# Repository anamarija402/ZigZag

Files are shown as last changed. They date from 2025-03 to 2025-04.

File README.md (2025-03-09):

## RadionaOrg ZigZag badge

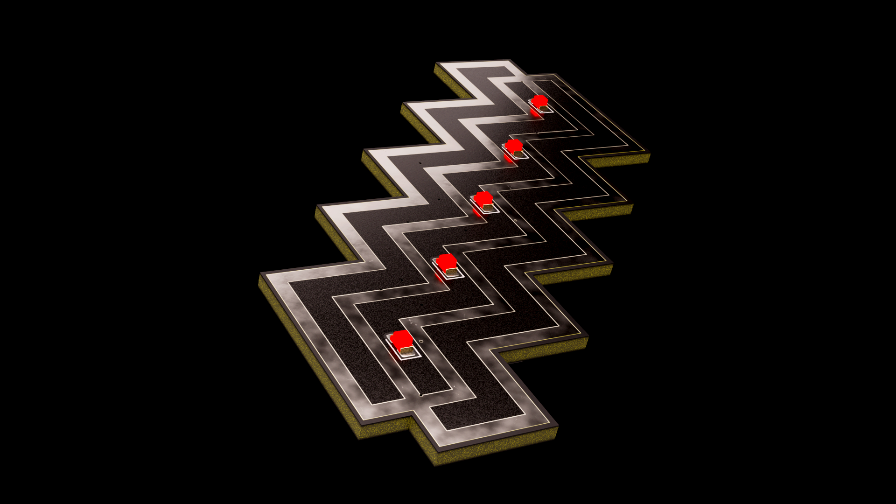
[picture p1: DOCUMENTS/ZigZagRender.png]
ZigZag


### Request and starting point

We got request from BSidesZG to design some blink LED badge with some interesting task to solve.

https://www.bsideszagreb.com/

As badge may slightly change over time here is aditional README for BSidesZG

BSidesZG README

Starting point for our badge was RVPC from Olimex, we have preserved most of schematics, and added LEDs

The EURO 1.00 Risc-V personal computer with VGA and Keyboard and Woz like monitor. The purpose of this project is to make educational platform which people can use to learn RISCV assembler and experiment like in the old days in 1980s :)

https://www.olimex.com/Products/Retro-Computers/RVPC/open-source-hardware

We whare also inspired with BalCCon badge that is using same chip.

https://2k25.balccon.org/

### Few of ideas we wanted to test

- [x] Keep it simple
- [x] Keep it low cost
- [x] Should solderable by hand
- [x] Input and outputs are needed
- [x] Tasks can be quickly changed added
- [x] It needs to be cheap to order assembled
- [x] Use most standard COIN CELL battery CR2032
- [x] Unique design that is connected to Radiona (ZigZag)
- [x] Badge should not draing to much current so it can survive conference day

### Why 5 LEDs?

With less then 5 LEDs we could do blinky, but with 5 we can do PoV

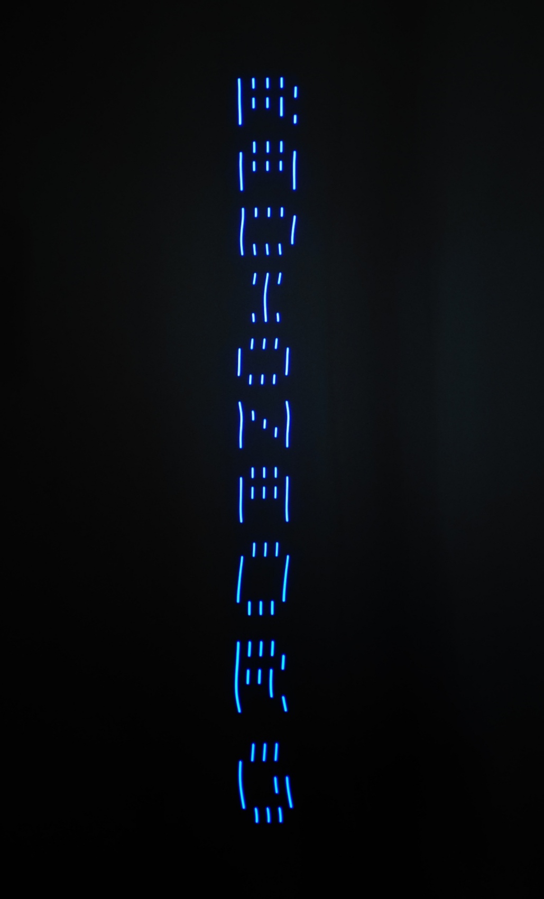
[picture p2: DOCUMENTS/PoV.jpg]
PoV


As we have BLUE and RED team, we have tested BLUE and RED LEDs.

RED LED are consuming less, and morse is better readable.

### Why Only one button?

We only have 6 pins, and we did not want to intraduce any aditinal chip.

And there are many things we can do with one button.

Considerring that we can have short press, long press, longer press, double press, tripple press - you get the point that one button should be enough for everything...

### Why those component and why 0603

We are using 0603 resistors and 0805 LEDs as they are still hand solderable, and we are using those on ULX3S so we can recycle components from scraped boards...

### Assembly

We wanted to confirm hand assembly, and low batch DIY assembly so we did first badge by hand, and rest of 69 badges with stencil. 
We baked first batch in oven but also checked paper stancil + hot air, and all works fine.

Paper is just 80g color paper. Diode laser cuts some colors better so we are using orange one.

For PCB holder we are using cuted cardboard

And for BOTTOM side we are using standoff cutter from hammer paper.

Applying paste to front side

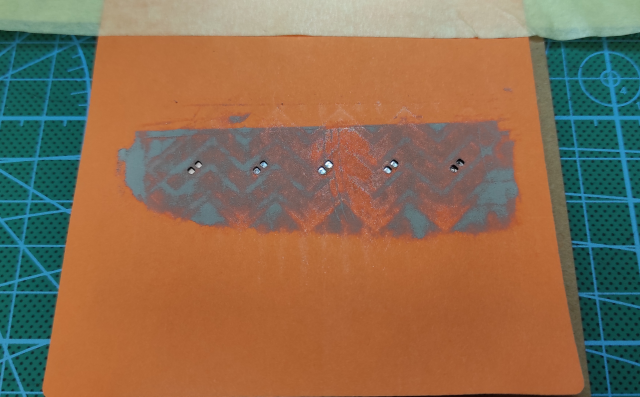
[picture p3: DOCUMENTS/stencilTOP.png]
Applying paste for LEDs


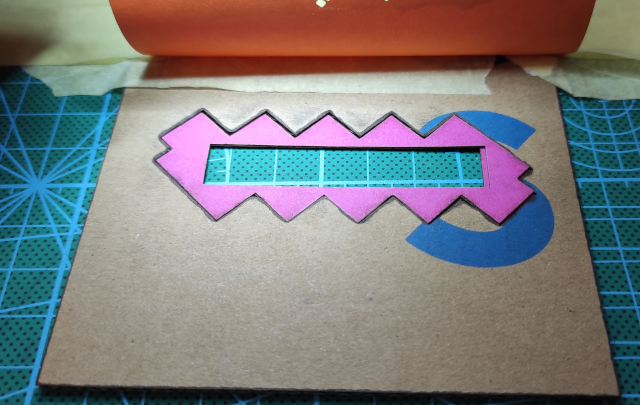
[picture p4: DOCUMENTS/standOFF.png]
StandOFF


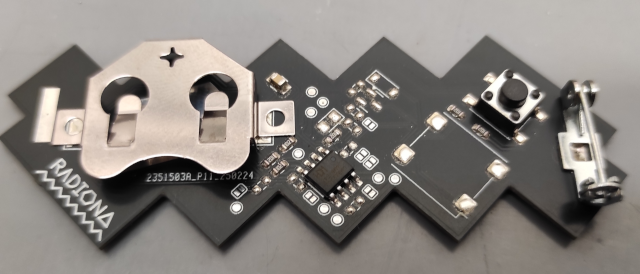
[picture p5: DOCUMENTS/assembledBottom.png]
Asembled Bottom


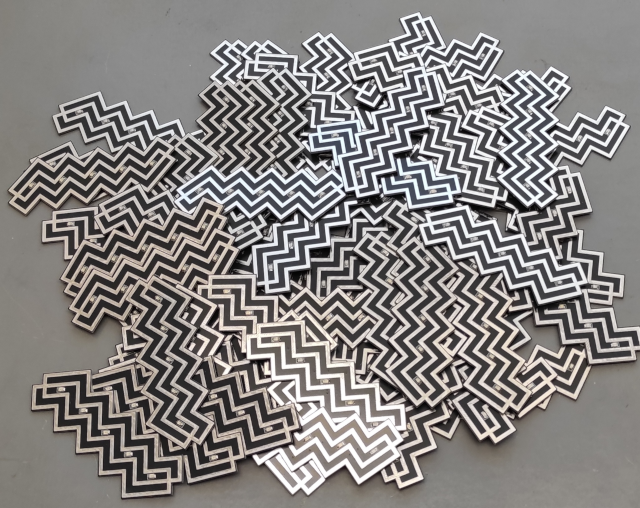
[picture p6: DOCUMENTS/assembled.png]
Assebled


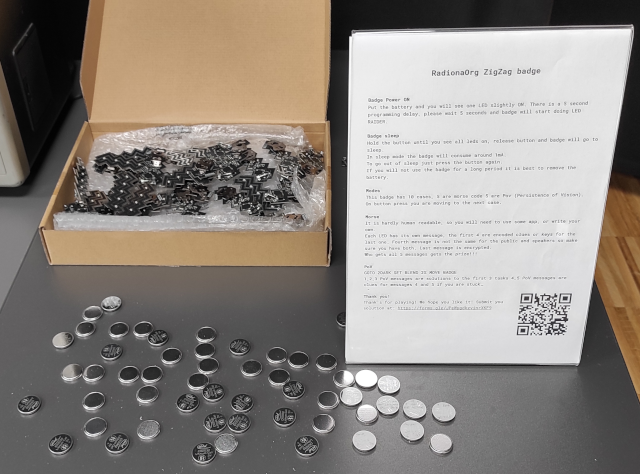
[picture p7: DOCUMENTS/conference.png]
Conference


### Implemented features

- [x] Fancy raider blinking
- [x] Morse used for output messages
- [x] PoV used for clues and solutions
- [x] Short button press
- [x] Long button press
- [ ] Other types of button presses
- [x] Sleep mode
- [ ] Deep sleep mode

### Make it hackable!

We did not want to remove any RVPC component so with moving few resistors and closing jumpers you could even have RVPC with VGA, PS2 and speaker...

### Badge software

https://github.com/RadionaOrg/ZigZag/tree/main/SOFTWARE/PlatformIO/ZigZag

We are using VScode + PlatformIO for building and flash.sh for flashing...

### Programming

We are using raspberry pico and this software for programming https://github.com/aappleby/picorvd 

Be warned not to remove initial 5 sec delay if you want to keep badge programmable with picorvd.

For programming you only need GND and PD6 test point.

### Test points

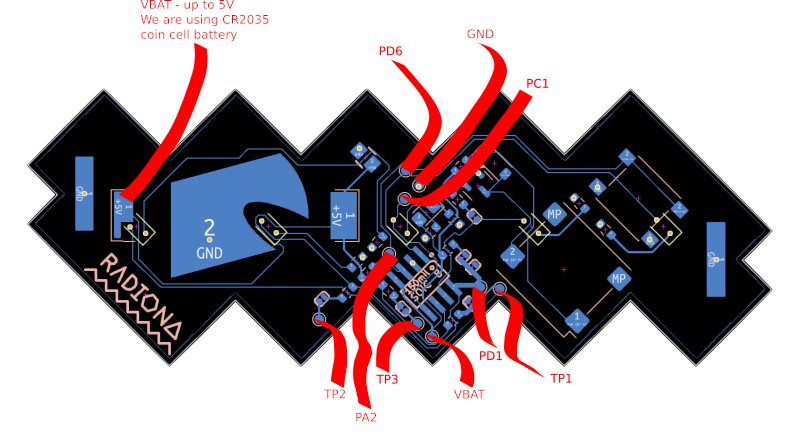
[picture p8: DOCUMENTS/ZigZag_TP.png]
TestPoints


### Schematic

ZigZag

### Licensee
* Hardware is released under CERN Open Hardware Licence Version 2 - Strongly Reciprocal
* Software is released under GPL V3 Licensee
* Documentation is released under CC BY-SA 4.0

Top side PCB design by Damir Prizmić
Back side PCB design by Goran Mahovlić

Idea: BSidesZG, Ante Jurjević, Damir Prizmić, Goran Mahovlić, kost, 1g0r, BalCCon Badge, Olimex RVPC

Code:  Goran Mahovlić 

Big thanks to Olimex for all RVPC code examples...

### Events

| Event  | No. of badges | Offered Solutions | Accepted solutions |
| --- | --- | --- | --- |
| BSidesZG | 70 | 1 | 1 |

### Badge solvers

| Event  | Date | Name | Needed time |
| --- | --- | --- |-----|
| BSidesZG | 07.03.2025. | Jurica Radović |~4h |

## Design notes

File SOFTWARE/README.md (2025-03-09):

# PlatformIO
The PlatformIO folder contains badge demo project

# Tools

Check original RVPCproject for programming with ESP32

https://github.com/OLIMEX/RVPC/tree/main/SOFTWARE

pvpc folder contain all tools you will need to program ESP32-S2-DevKitLiPo-USB to act as programmer and the minichlink which used the ESP32-S2 to program CH32V003
Follow the instructions in the user manual

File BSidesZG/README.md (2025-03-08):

# RadionaOrg ZigZag badge for BSidesZG

ZigZag

### Badge Power ON

Put battery and you will see one LED slightly ON.

There is 5 second programming delay, please wait 5 seconds and badge will start doing LED RAIDER.

### Badge sleep

Hold button until you see all leds on, release button and badge will go to sleep.

In sleep mode badge will consume around 1mA.

To go out of sleep just press button again.

If you will not use badge for long period it is best to remove battery.

### Modes

This badge has 10 cases, 5 are morse code 5 are Pov ( Persistance of Vision ).

On button press you are moving to next case.

### Morse 

It is hardly human readable, so you will need to use some app, or write your own...

Each LED has it's own message, first 4 are encoded clues or keys for last one.

Fourth message is not the same for public and spaekers so make sure you have both.

Last message is encrypted.

Who gets all 5 messages gets the prize!!!

### PoV

GOTO 2DARK

SET BLEND 2S

MOVE BADGE

1,2,3 PoV messages are solutions to first 3 tasks
4,5 PoV messages are clues for messages 4 and 5 if you are stucked...

## Thank you!

Thank's for playing! We hope you like it!

## Licensee
* Hardware is released under CERN Open Hardware Licence Version 2 - Strongly Reciprocal
* Software is released under GPL V3 Licensee
* Documentation is released under CC BY-SA 4.0

Top side PCB design by Damir Prizmić
Back side PCB design by Goran Mahovlić

Idea: BSidesZG, Ante Jurjević, Damir Prizmić, Goran Mahovlić, kost, 1g0r, BalCCon Badge, Olimex RVPC

Code:  Goran Mahovlić 

Big thanks to Olimex for all RVPC code examples...

Known problems (HW): Battery holder footprint is not good, if you push battery to end position it can brick battery

Known problems (SW): In one key you will nottice missing H letter (gramar) - use your key as is ignore gramar.

### Events

| Event  | No. of badges | Offered Solutions | Accepted solutions |
| --- | --- | --- | --- |
| BSidesZG | 70 | 1 | 1 |

### Badge solvers

| Event  | Date | Name |
| --- | --- | --- |
| BSidesZG | 07.03.2025. | Jurica Radović |

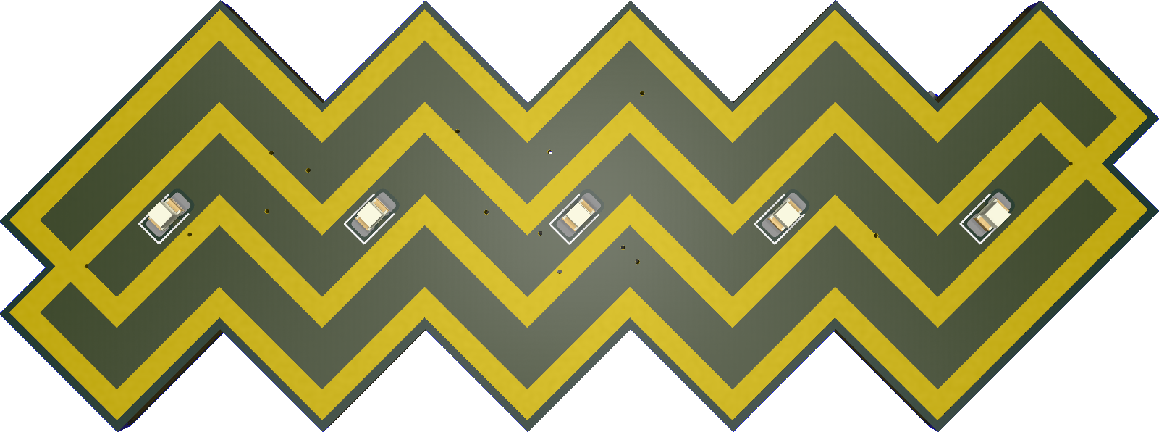
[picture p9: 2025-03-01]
DOCUMENTS/ZigZag.png

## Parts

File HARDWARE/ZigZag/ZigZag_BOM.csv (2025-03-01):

Quantity | Value | Footprint | Reference
1 | 100nF/25V/2010 | C2010 | C1
1 | 1N4148/DO35 | DO35_1K_2A | D1
1 | HN1x2 | HN1x2 | PGM/DBG1
1 | MDR6_MINI-DIN | PS2_MDR6_MINI-DIN | PS2_KBD1
1 | PWRJ-2mm(YDJ-1134) | PWRJ-2mm(YDJ-1136) | PWR_JACK1
1 | LED/PTH/5MM/RED | LED-5mm-PTH-KA | PWR_LED1
4 | 2k/1/8W | R_0.125W_PTH | R1, R5, R6, R8
3 | 470R/1/8W | R_0.125W_PTH | R2, R3, R4
1 | 100R/1/8W | R_0.125W_PTH | R7
1 | Speaker_QMB-09B-03(1.5-5.0V_2.7kHz_F9.0mm*H5.5mm) | Speaker_QMB-09B-03_1-Plus_2-Minus | SPK1
1 | 2N3904 | TO-92_PTH | T1
1 | CH32V003J4M6(SOP8) | SOIC-8_150mil | U1
1 | HDR15-3.08-14.5T/VGA15/14.5mm | VGA15-F(HDR15-3.08-14.5T)_DrillSlot | VGA1

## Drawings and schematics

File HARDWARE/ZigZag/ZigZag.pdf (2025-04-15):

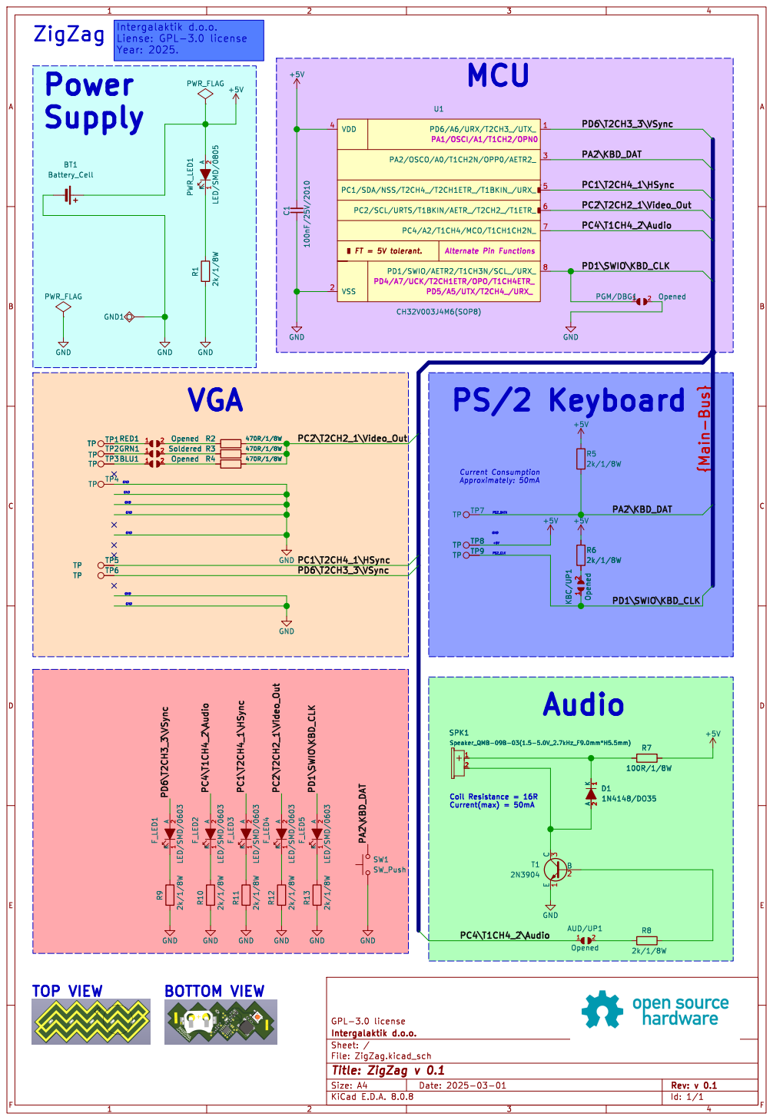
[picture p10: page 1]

2 F_LED4 LED/SMD/0603 GND GND GND1 PWR_FLAG

2 F_LED5 LED/SMD/0603 BLU1 1 2 Opened GRN1 1 2 Soldered TP5 TP R13 2k/1/8W

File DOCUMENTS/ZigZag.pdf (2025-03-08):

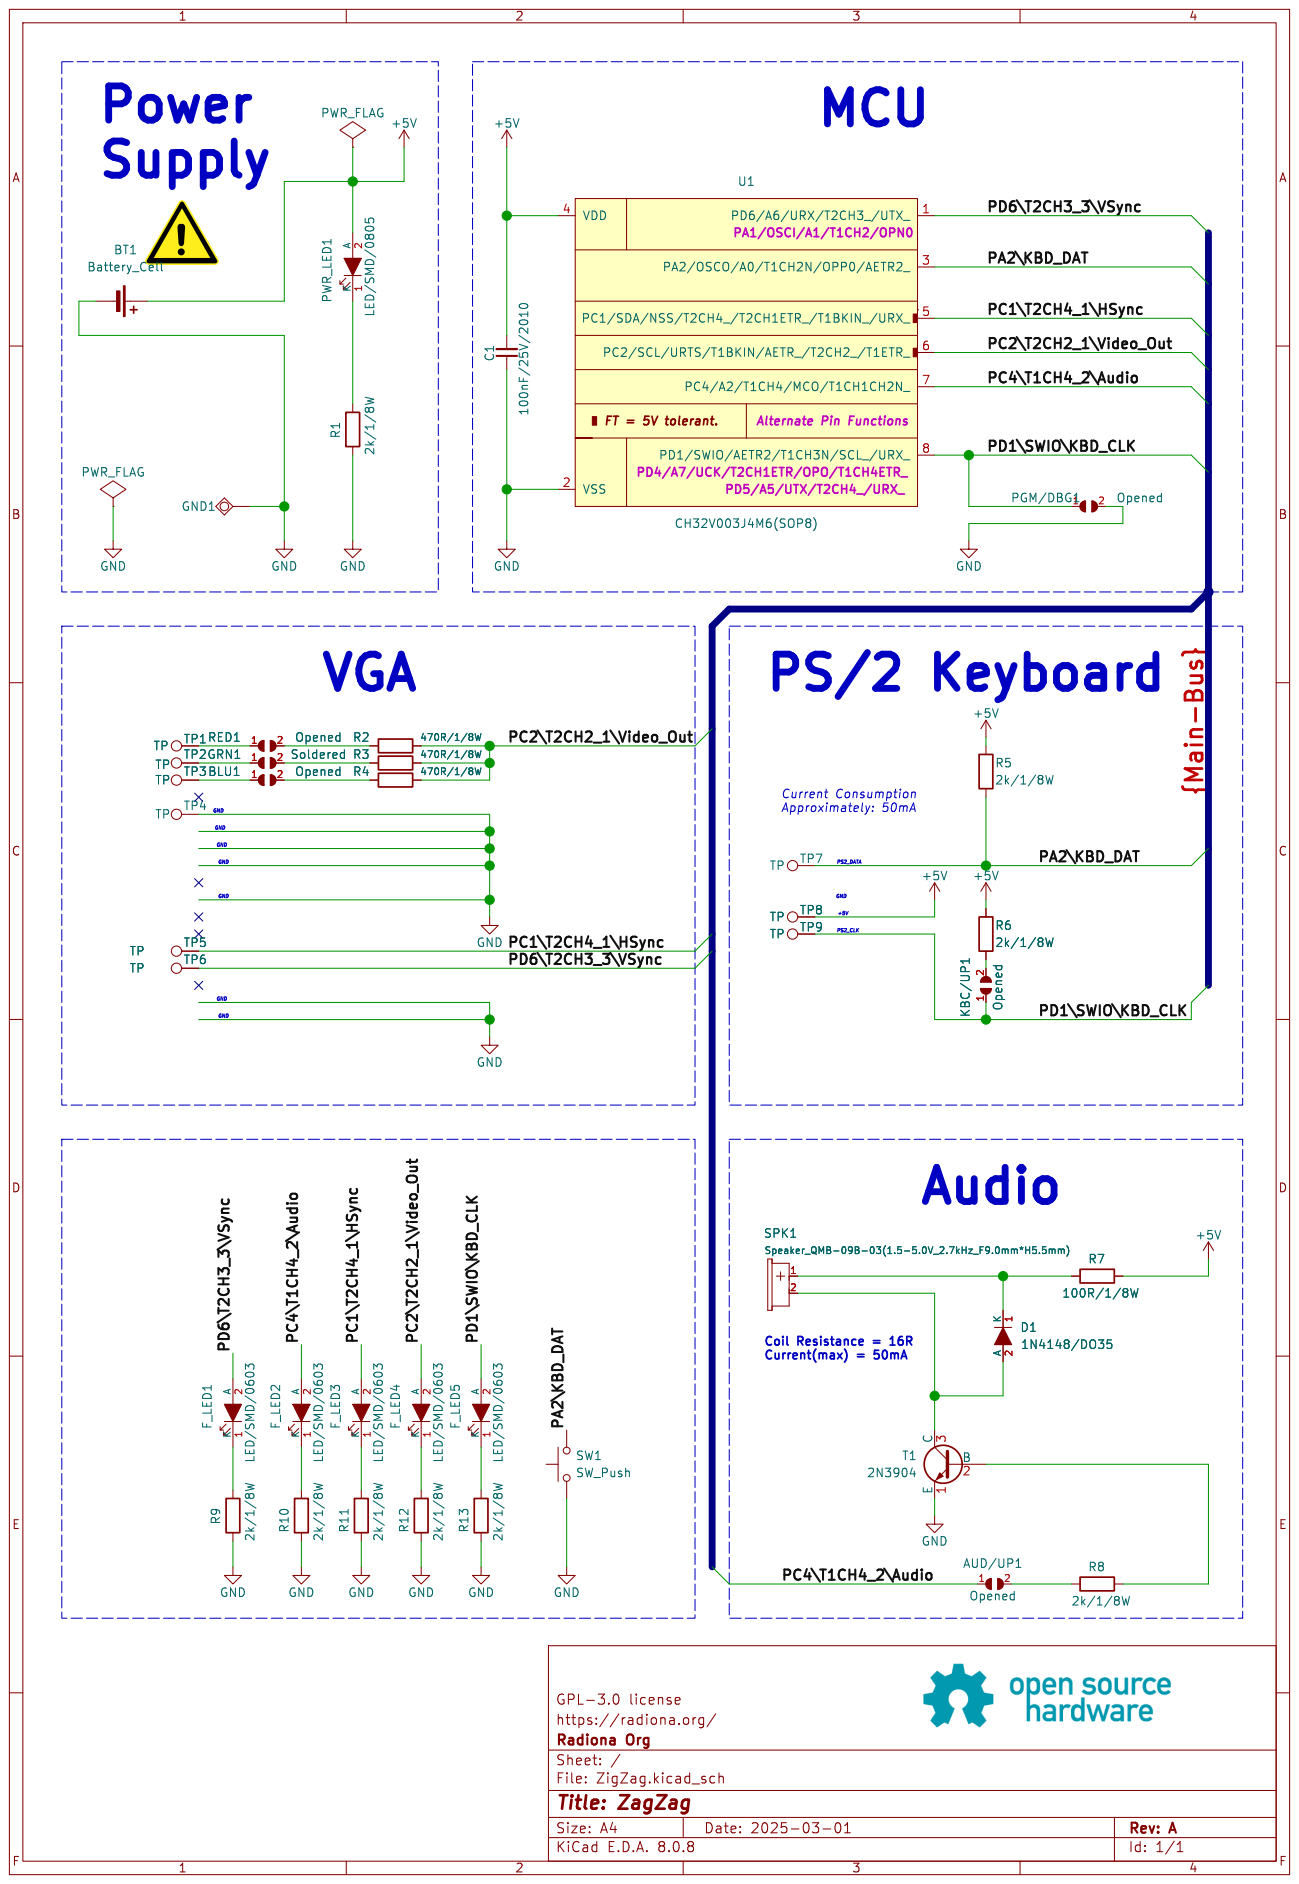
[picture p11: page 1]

2 F_LED1 LED/SMD/0603 GND GND

File: ZigZag.kicad_sch Sheet: / Radiona Org

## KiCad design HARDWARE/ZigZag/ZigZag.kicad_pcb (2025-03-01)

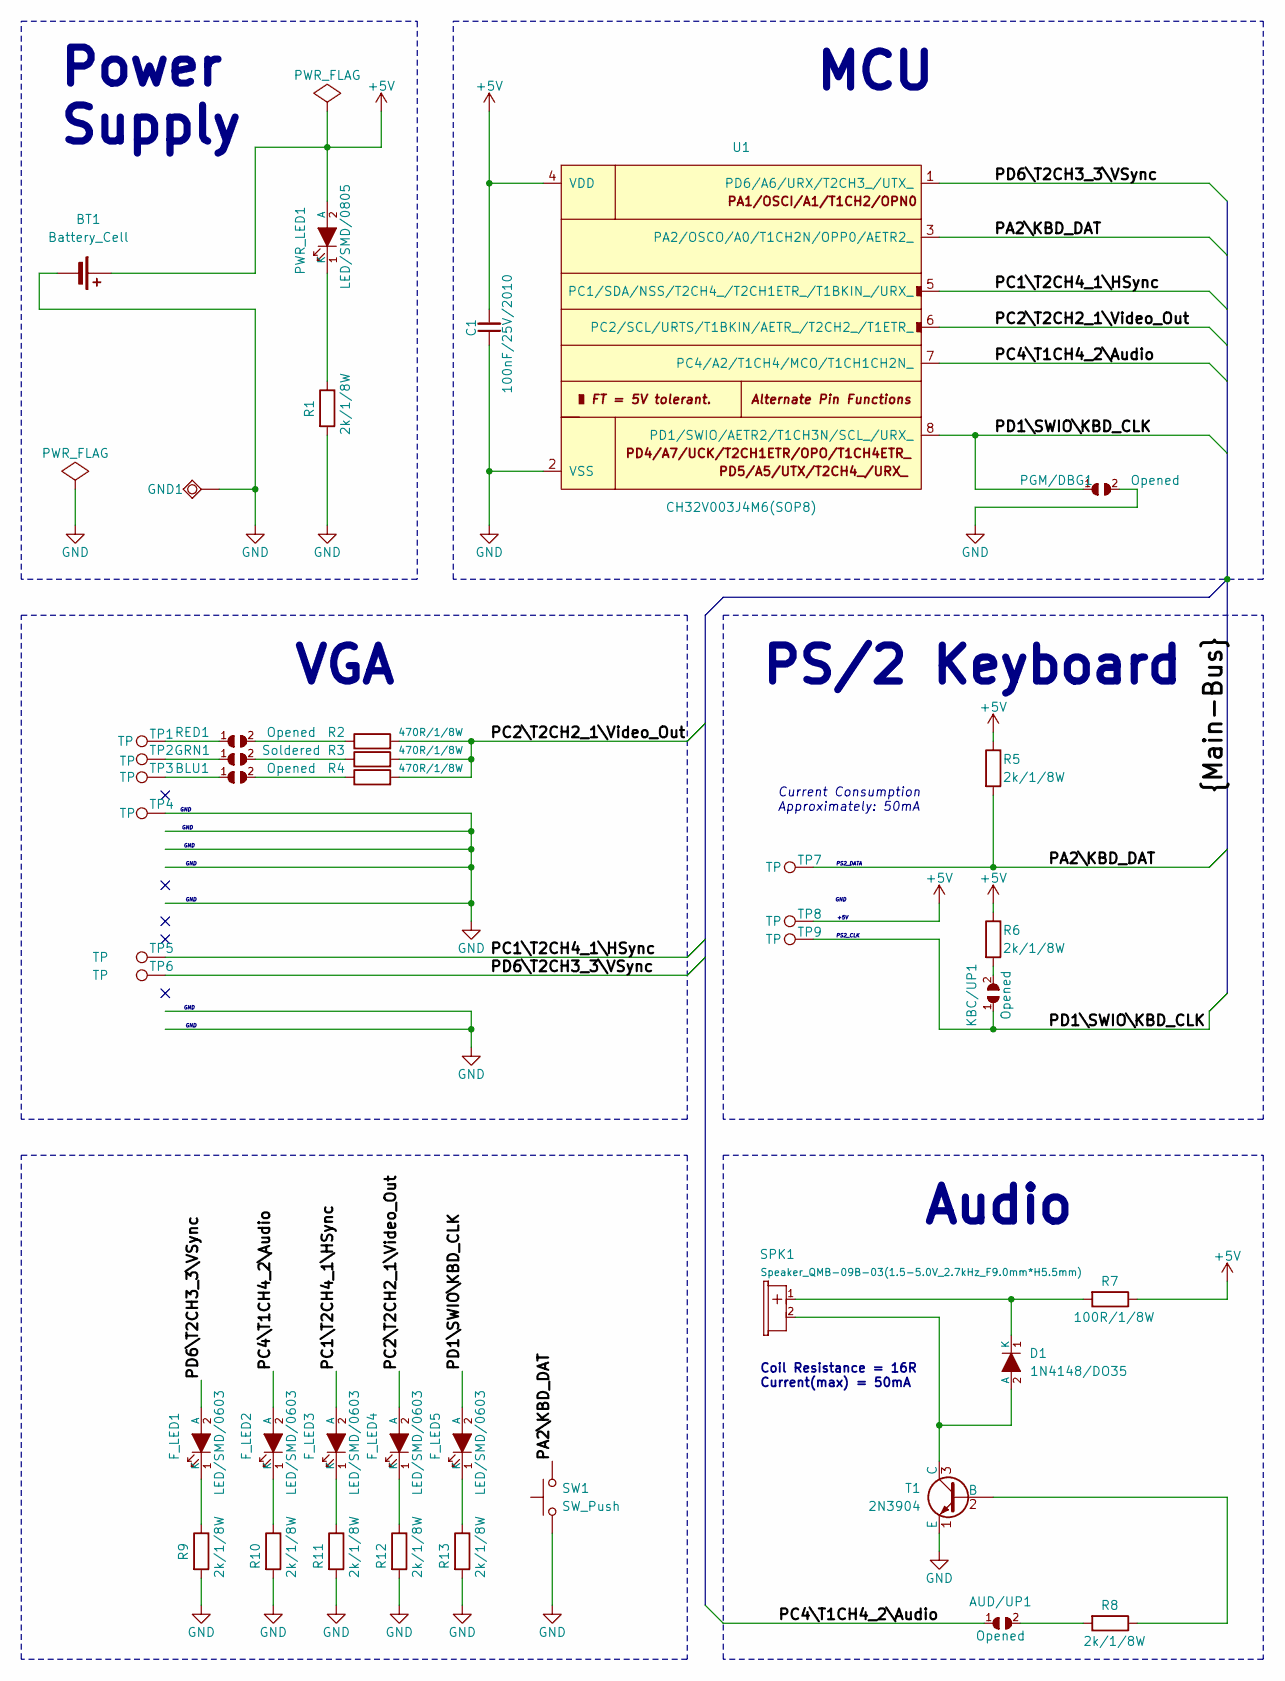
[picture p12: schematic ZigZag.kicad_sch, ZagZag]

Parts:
AUD/UP1: Opened; SJ_1_SMALLER
BLU1: Opened; SJ_1_SMALLER
BT1: Battery_Cell; BatteryHolder_Keystone_3002_1x2032
C1: 100nF/25V/2010; C_0805_5MIL_DWS
D1: 1N4148/DO35; D_SOD-123
F_LED1, F_LED2, F_LED3, F_LED4, F_LED5: LED/SMD/0603; LED_0805_2012Metric_Pad1.15x1.40mm_HandSolder
GND1: TESTPAD; arc_90_0.5
GRN1: Soldered; SJ_1_SMALLER
KBC/UP1: Opened; SJ_1_SMALLER
PGM/DBG1: Opened; SJ_1_SMALLER
PWR_LED1: LED/SMD/0805; LED_0805_2012Metric_Pad1.15x1.40mm_HandSolder
R1, R5, R6, R8, R9, R10, R11, R12, R13: 2k/1/8W; R_0603_1608Metric
R2, R3, R4: 470R/1/8W; R_0603_1608Metric
R7: 100R/1/8W; R_0603_1608Metric
RED1: Opened; SJ_1_SMALLER
SPK1: Speaker_QMB-09B-03(1.5-5.0V_2.7kHz_F9.0mm*H5.5mm); MagneticBuzzer_PUI_SMT-1028-T-2-R
SW1: SW_Push; SW_SPST_PTS645
T1: 2N3904; SOT-23
TP1, TP2, TP3, TP4, TP5, TP6, TP7, TP8, TP9: TP; TestPoint_Pad_D1.0mm
U1: CH32V003J4M6(SOP8); SOIC-8_150mil

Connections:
+5V: BT1.1 (+), C1.2, PWR_LED1.2 (A), R5.1, R6.1, R7.1, TP8.1, U1.4 (VDD)
/PA2\KBD_DAT: R5.2, SW1.2, TP7.1, U1.3 (PA2/OSCO/A0/T1CH2N/OPP0/AETR2_)
/PC1\T2CH4_1\HSync: F_LED3.2 (A), TP5.1, U1.5 (PC1/SDA/NSS/T2CH4_/T2CH1ETR_/T1BKIN_/UR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)
/PC2\T2CH2_1\Video_Out: F_LED4.2 (A), R2.2, R3.2, R4.2, U1.6 (PC2/SCL/URTS/T1BKIN/AETR_/T2CH2_/T1ETR_)
/PC4\T1CH4_2\Audio: AUD/UP1.1, F_LED2.2 (A), U1.7 (PC4/A2/T1CH4/MCO/T1CH1CH2N_)
/PD1\SWIO\KBD_CLK: F_LED5.2 (A), KBC/UP1.1, PGM/DBG1.1, TP9.1, U1.8 (PD1/SWIO/AETR2/T1CH3N/SCL_/URX_)
/PD6\T2CH3_3\VSync: F_LED1.2 (A), TP6.1, U1.1 (PD6/A6/URX/T2CH3_/UTX_)
GND: BT1.2 (-), C1.1, GND1.1 (Pad), PGM/DBG1.2, R1.2, R9.2, R10.2, R11.2, R12.2, R13.2, SW1.1, T1.1 (E), TP4.1, U1.2 (VSS); also elsewhere on the board
unnamed: AUD/UP1.2, R8.2
unnamed: BLU1.1, TP3.1
unnamed: BLU1.2, R4.1
unnamed: D1.2 (A), SPK1.2 (MINUS), T1.3 (C)
unnamed: D1.1 (K), R7.2, SPK1.1 (PLUS)
unnamed: F_LED1.1 (K), R9.1
unnamed: F_LED2.1 (K), R10.1
unnamed: F_LED3.1 (K), R11.1
unnamed: F_LED4.1 (K), R12.1
unnamed: F_LED5.1 (K), R13.1
unnamed: GRN1.1, TP2.1
unnamed: GRN1.2, R3.1
unnamed: KBC/UP1.2, R6.2
unnamed: PWR_LED1.1 (K), R1.1
unnamed: R2.1, RED1.2
unnamed: RED1.1, TP1.1
unnamed: R8.1, T1.2 (B)

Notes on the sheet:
Power Supply
GND
PS/2 Keyboard
PS2_CLK
Current Consumption Approximately: 50mA
MCU
+5V
PS2_DATA
VGA
Audio
Coil Resistance = 16R Current(max) = 50mA

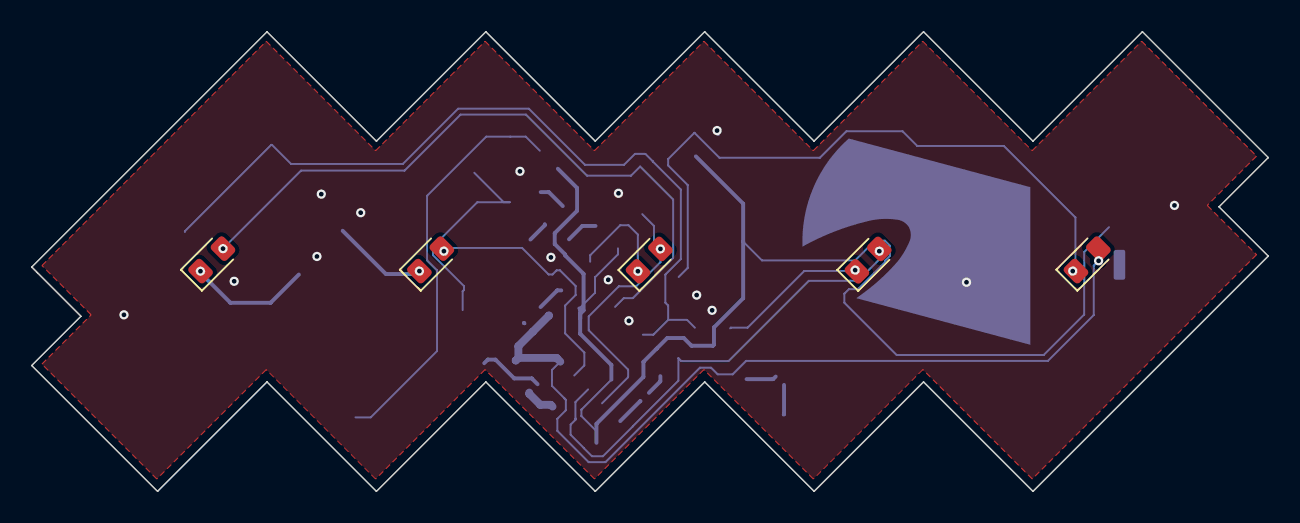
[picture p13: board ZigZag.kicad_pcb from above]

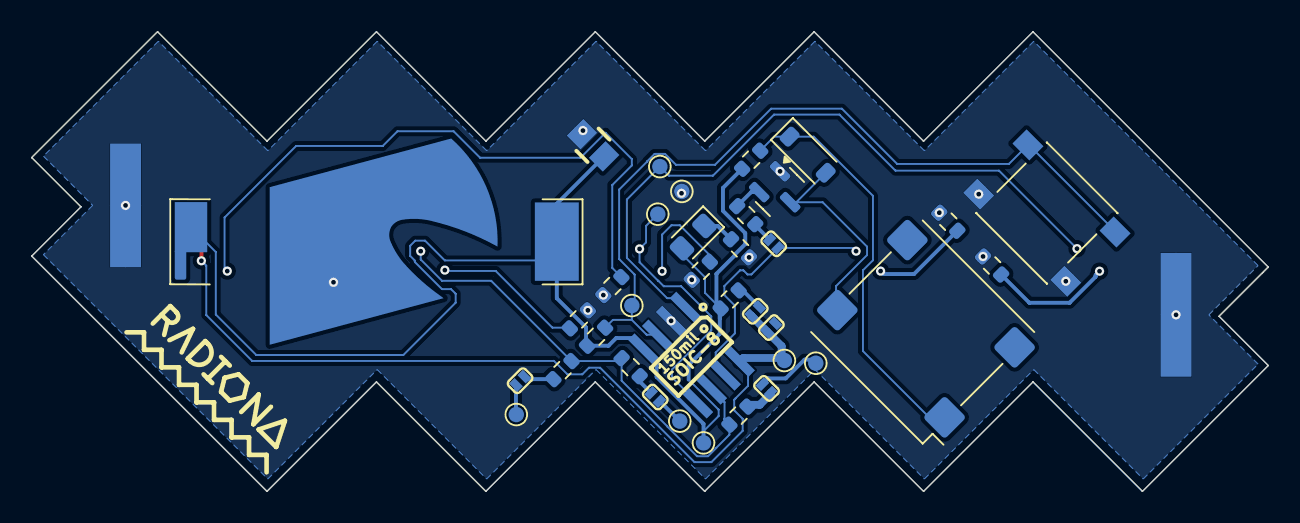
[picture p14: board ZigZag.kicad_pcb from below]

Board: 2 copper layers, 79.9 x 29.7 mm, 44 parts (39 on the bottom side), 25 nets.

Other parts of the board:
GND1#2: TESTPAD; arc_90_0.5
radiona: radiona

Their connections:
GND: GND1#2.1 (Pad); also elsewhere on the board

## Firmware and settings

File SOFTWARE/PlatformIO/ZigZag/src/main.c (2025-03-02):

/**
 * ZigZag badge
 *
 * @authors
 * Copyright (C) 2025 Goran Mahovlić <goran.mahovlic@intergalaktik.eu>
 *
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
 * You should have received a copy of the GNU General Public License along with
 * this program.  If not, see <http://www.gnu.org/licenses/>.
 */

#include <ch32v00x.h>
#include <ch32v00x_pwr.h>
#include <ch32v00x_rcc.h>
#include <ch32v00x_exti.h>
#include <debug.h>
#include <string.h>

void NMI_Handler(void)       __attribute__((interrupt("WCH-Interrupt-fast")));
void HardFault_Handler(void) __attribute__((interrupt("WCH-Interrupt-fast")));

#define SYSCLK_FREQ_8MHz_HSI    8000000

#define ROW_DELAY_MS 30
#define RAIDER_DELAY_MS 100
#define LOOP_DELAY_MS 3000
#define PROGRAMMING_DELAY 5000
#define NUMBER_OF_CASES 3

// Define timing (adjustable)
#define DOT_DURATION  200
#define DASH_DURATION 600
#define SYMBOL_SPACE  200  // Space between dot/dash
#define LETTER_SPACE  600  // Space between letters
#define WORD_SPACE    1400 // Space between words

uint8_t counter = 0;
uint32_t long_press_counter = 0;
uint8_t interrupt = 0;
uint8_t long_press = 0;

const uint8_t font_5x5[37][5] = {
    // A-Z
    {0x0E, 0x11, 0x1F, 0x11, 0x11},  // A
    {0x1E, 0x11, 0x1E, 0x11, 0x1E},  // B
    {0x0E, 0x11, 0x10, 0x11, 0x0E},  // C
    {0x1E, 0x11, 0x11, 0x11, 0x1E},  // D
    {0x1F, 0x10, 0x1E, 0x10, 0x1F},  // E
    {0x1F, 0x10, 0x1E, 0x10, 0x10},  // F
    {0x0E, 0x10, 0x13, 0x11, 0x0E},  // G
    {0x11, 0x11, 0x1F, 0x11, 0x11},  // H
    {0x0E, 0x04, 0x04, 0x04, 0x0E},  // I
    {0x01, 0x01, 0x01, 0x11, 0x0E},  // J
    {0x11, 0x12, 0x1C, 0x12, 0x11},  // K
    {0x10, 0x10, 0x10, 0x10, 0x1F},  // L
    {0x11, 0x1B, 0x15, 0x11, 0x11},  // M
    {0x11, 0x19, 0x15, 0x13, 0x11},  // N
    {0x0E, 0x11, 0x11, 0x11, 0x0E},  // O
    {0x1E, 0x11, 0x1E, 0x10, 0x10},  // P
    {0x0E, 0x11, 0x11, 0x13, 0x0F},  // Q
    {0x1E, 0x11, 0x1E, 0x12, 0x11},  // R
    {0x0F, 0x10, 0x0E, 0x01, 0x1E},  // S
    {0x1F, 0x04, 0x04, 0x04, 0x04},  // T
    {0x11, 0x11, 0x11, 0x11, 0x0E},  // U
    {0x11, 0x11, 0x11, 0x0A, 0x04},  // V
    {0x11, 0x11, 0x15, 0x1B, 0x11},  // W
    {0x11, 0x0A, 0x04, 0x0A, 0x11},  // X
    {0x11, 0x0A, 0x04, 0x04, 0x04},  // Y
    {0x1F, 0x02, 0x04, 0x08, 0x1F},  // Z

    // 0-9
    {0x0E, 0x11, 0x11, 0x11, 0x0E},  // 0
    {0x04, 0x0C, 0x04, 0x04, 0x0E},  // 1
    {0x0E, 0x01, 0x0E, 0x10, 0x1F},  // 2
    {0x0E, 0x01, 0x06, 0x01, 0x0E},  // 3
    {0x02, 0x06, 0x0A, 0x1F, 0x02},  // 4
    {0x1F, 0x10, 0x1E, 0x01, 0x1E},  // 5
    {0x0E, 0x10, 0x1E, 0x11, 0x0E},  // 6
    {0x1F, 0x01, 0x02, 0x04, 0x08},  // 7
    {0x0E, 0x11, 0x0E, 0x11, 0x0E},  // 8
    {0x0E, 0x11, 0x0F, 0x01, 0x0E},  // 9

    // Dash (-)
    {0x00, 0x00, 0x1F, 0x00, 0x00}   // -
};

// Morse Code Dictionary (A-Z, 0-9)
const char* MORSE_TABLE[36] = {
    ".-", "-...", "-.-.", "-..", ".", "..-.", "--.", "....", "..", ".---",  // A-J
    "-.-", ".-..", "--", "-.", "---", ".--.", "--.-", ".-.", "...", "-",   // K-T
    "..-", "...-", ".--", "-..-", "-.--", "--..",                          // U-Z
    "-----", ".----", "..---", "...--", "....-", ".....", "-....", "--...", "---..", "----." // 0-9
};

// Convert character to Morse code
const char* char_to_morse(char c) {
    if (c >= 'A' && c <= 'Z') return MORSE_TABLE[c - 'A'];  // Letters
    if (c >= 'a' && c <= 'z') return MORSE_TABLE[c - 'a'];  // Lowercase
    if (c >= '0' && c <= '9') return MORSE_TABLE[c - '0' + 26]; // Numbers
    return NULL; // Unsupported character
}

volatile uint8_t sleep_mode = 0;

void DelayIfBTN_Ms(uint32_t n){
	uint32_t current_delay = 0;

	while(GPIO_ReadInputDataBit(GPIOA, GPIO_Pin_2) && current_delay<n){
		Delay_Ms(1);
		current_delay++;
	}

}

void ledWrite(uint8_t led, uint8_t state){
	if(led>=0 && led<5){ // if LED exists
		if(led==0){GPIO_WriteBit(GPIOD, GPIO_Pin_6, state);} // 1
		else if(led==1){GPIO_WriteBit(GPIOC, GPIO_Pin_1, state);} // 2
		else if(led==2){GPIO_WriteBit(GPIOC, GPIO_Pin_2, state);} // 3
		else if(led==3){GPIO_WriteBit(GPIOC, GPIO_Pin_4, state);} // 4
		else if(led==4){GPIO_WriteBit(GPIOD, GPIO_Pin_4, state);} // 5
	}
}

void ledsOFF(void){
	for (uint8_t i=0;i<5;i++){
		ledWrite(i,0);
	}
}

void ledsON(void){
	for (uint8_t i=0;i<5;i++){
		ledWrite(i,1);
	}
}

void EXTI7_0_IRQHandler(void) __attribute__((interrupt("WCH-Interrupt-fast")));
void EXTI7_0_IRQHandler(void){
    if (EXTI->INTFR & (1 << 2)) // Check if PA2 caused the interrupt
    {
		interrupt=1;
    }
	EXTI_ClearITPendingBit(EXTI_Line2);
}

// Function to blink Morse code
void blink_string(const char* text, uint8_t led) {
	if(led>=0 && led<5){
    while (*text) {
        if (*text == ' ') {
            Delay_Ms(WORD_SPACE);  // Space between words
        } else {
            const char* morse = char_to_morse(*text);
            if (morse) {
                while (*morse) {
                    if (*morse == '.') {
                        ledWrite(led,1);
                        DelayIfBTN_Ms(DOT_DURATION);
                    } else if (*morse == '-') {
                        ledWrite(led,1);
                        DelayIfBTN_Ms(DASH_DURATION);
                    }
                    ledWrite(led,0);  // Turn off LED
                    DelayIfBTN_Ms(SYMBOL_SPACE);
                    morse++;
                }
                DelayIfBTN_Ms(LETTER_SPACE); // Space between letters
            }
        }
        text++; // Move to next character
    }
	}
}

void raider(void){
		ledWrite(0,1);
		DelayIfBTN_Ms(RAIDER_DELAY_MS);
		DelayIfBTN_Ms(RAIDER_DELAY_MS);		
		ledWrite(0,0);
		ledWrite(1,1);
		DelayIfBTN_Ms(RAIDER_DELAY_MS);
		ledWrite(1,0);
		ledWrite(2,1);
		DelayIfBTN_Ms(RAIDER_DELAY_MS);		
		ledWrite(2,0);
		ledWrite(3,1);
		DelayIfBTN_Ms(RAIDER_DELAY_MS);
		ledWrite(3,0);
		ledWrite(4,1);
		DelayIfBTN_Ms(RAIDER_DELAY_MS);
		DelayIfBTN_Ms(RAIDER_DELAY_MS);		
		ledWrite(4,0);
		ledWrite(3,1);
		DelayIfBTN_Ms(RAIDER_DELAY_MS);
		ledWrite(3,0);
		ledWrite(2,1);
		DelayIfBTN_Ms(RAIDER_DELAY_MS);
		ledWrite(2,0);
		ledWrite(1,1);
		DelayIfBTN_Ms(RAIDER_DELAY_MS);		
		ledWrite(1,0);
}

void displayCharacter(char c, int scrollSpeed) {
    int index;
    
    if (c >= 'A' && c <= 'Z') {
        index = c - 'A';  // Map 'A' to index 0
    } else if (c >= '0' && c <= '9') {
        index = c - '0' + 26;  // Map '0' to index 26
    } else if (c == '-') {
        index = 36;  // Index for '-'
    } else {
        return;  // Invalid character, do nothing
    }

    for (int col = 0; col < 5; col++) {
        uint8_t columnData = font_5x5[index][col];  // Get column bitmap
        for (int row = 0; row < 5; row++) {
            ledWrite(row, (columnData >> row) & 1);  // Set LEDs
        }
       Delay_Ms(ROW_DELAY_MS);  // Adjust for PoV effect
    }

		ledsOFF();
        Delay_Ms(ROW_DELAY_MS);  // Adjust for PoV effect	
}

void scrollText(const char *text, int scrollSpeed) {
    int len = strlen(text);

    for (int i = 0; i < len; i++) {
        displayCharacter(text[i], scrollSpeed);  // Use your existing function
        DelayIfBTN_Ms(scrollSpeed);  // Adjust for PoV effect
		if(!GPIO_ReadInputDataBit(GPIOA, GPIO_Pin_2)){
			break;
		}
    }
}

/** Enable Interrupt falling edge A2*/
void EXTI0_INT_INIT (void)
{
  AFIO->PCFR1 = AFIO->PCFR1 & 0xFFFF7FFF; //Sets PA1 & PA2 as I/O by clearing bit 15  As we are not using external oscilator

  GPIO_InitTypeDef GPIO_InitStructure = {0};
  EXTI_InitTypeDef EXTI_InitStructure = {0};
  NVIC_InitTypeDef NVIC_InitStructure = {0};

  RCC_APB2PeriphClockCmd(RCC_APB2Periph_AFIO | RCC_APB2Periph_GPIOA, ENABLE);

  GPIO_InitStructure.GPIO_Pin = GPIO_Pin_2;
  GPIO_InitStructure.GPIO_Mode = GPIO_Mode_IPU;
  GPIO_InitStructure.GPIO_Speed = GPIO_Speed_2MHz;
  GPIO_Init(GPIOA, &GPIO_InitStructure);

  /* GPIOA ----> EXTI_Line2 */
  GPIO_EXTILineConfig(GPIO_PortSourceGPIOA, GPIO_PinSource2);
  EXTI_InitStructure.EXTI_Line = EXTI_Line2;
  EXTI_InitStructure.EXTI_Mode = EXTI_Mode_Interrupt;
  EXTI_InitStructure.EXTI_Trigger = EXTI_Trigger_Falling;
  EXTI_InitStructure.EXTI_LineCmd = ENABLE;
  EXTI_Init(&EXTI_InitStructure);

  NVIC_InitStructure.NVIC_IRQChannel = EXTI7_0_IRQn; // external hardware interrupts
  NVIC_InitStructure.NVIC_IRQChannelPreemptionPriority = 0;
  NVIC_InitStructure.NVIC_IRQChannelSubPriority = 1;
  NVIC_InitStructure.NVIC_IRQChannelCmd = ENABLE;
  NVIC_Init(&NVIC_InitStructure);
}

int main(void) {
	NVIC_PriorityGroupConfig(NVIC_PriorityGroup_1);
	SystemCoreClockUpdate();
    
    Delay_Init();

	Delay_Ms(PROGRAMMING_DELAY);

	// GPIO configuration
	RCC_APB2PeriphClockCmd(RCC_APB2Periph_GPIOC, ENABLE);
	RCC_APB2PeriphClockCmd(RCC_APB2Periph_GPIOD | RCC_APB2Periph_AFIO, ENABLE);

	// Use the internal HSI oscillator
	RCC->CTLR |= (1 << 0);   // Enable HSI
	while (!(RCC->CTLR & (1 << 1))); // Wait for HSI to be ready

	RCC->CFGR0 &= ~(0x3);    // Select HSI as system clock (SW[1:0] = 00)

	// Disable HSE (external oscillator) completely if not used
	RCC->CTLR &= ~(1 << 16); // HSEON = 0
	RCC->CTLR &= ~(1 << 17); // HSEBYP = 0

	// Enable GPIOD & AFIO clock
	RCC->APB2PCENR |= (1 << 5) | (1 << 0);  // Enable GPIOD & AFIO

	// Ensure AFIO remap is not interfering with PD6
	AFIO->PCFR1 &= ~(1 << 15); // Keep PA1 & PA2 as GPIO
	AFIO->PCFR1 &= ~(1 << 24); // Ensure no remapping affects PD6

	GPIO_InitTypeDef cfgC = {0};
    cfgC.GPIO_Mode = GPIO_Mode_Out_PP;
   	cfgC.GPIO_Pin = GPIO_Pin_1 | GPIO_Pin_2 | GPIO_Pin_4;
	cfgC.GPIO_Speed = GPIO_Speed_2MHz;
    GPIO_Init(GPIOC, &cfgC);

	GPIO_InitTypeDef cfgD = {0};
    cfgD.GPIO_Mode = GPIO_Mode_Out_PP;
   	cfgD.GPIO_Pin = GPIO_Pin_4 | GPIO_Pin_6;
	cfgD.GPIO_Speed = GPIO_Speed_2MHz;
    GPIO_Init(GPIOD, &cfgD);

	EXTI0_INT_INIT();

	while (1) {

		//Debounce
		if (interrupt){
			interrupt=0;
				Delay_Ms(ROW_DELAY_MS);
				if(!GPIO_ReadInputDataBit(GPIOA, GPIO_Pin_2)){
					if(counter <= NUMBER_OF_CASES){ 
						counter++;
					}
					else{
						counter = 0;
					}
					while(!GPIO_ReadInputDataBit(GPIOA, GPIO_Pin_2)){
						long_press_counter++;
						if(long_press_counter>=1000000){
							long_press = 1;
							break;	
						}
					}
					long_press_counter = 0;
				}
		}

		if(long_press){
			ledsON();
			Delay_Ms(500);
			for(int i=0;i<5;i++){
				ledWrite(i,0);
				Delay_Ms(500);
			}
			long_press = 0;
			__WFI();
			counter = 1;
		}

		if(counter==0){
			__WFI(); // sleep mode waits for button press interrupt
		}
		else if(counter==1){
			raider();
			//ledWrite(0,1);
		}		
		else if(counter==2){
			blink_string("SOS",4);
			blink_string("SOS",3);
			blink_string("SOS",2);			
			blink_string("SOS",1);
			blink_string("SOS",0);
		}
		else if(counter==3){
			scrollText("RADIONA", ROW_DELAY_MS);  // Scroll text with a 200ms delay
			DelayIfBTN_Ms(LOOP_DELAY_MS);			
		}
	}
}

void NMI_Handler(void) {
	
}

void HardFault_Handler(void) {
	
	while (1) {

	}
}

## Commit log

2025-03-01 Removing RVPC - adding ZigZag
    [RVPC_Rev_A.kicad_pcb, RVPC_Rev_A.kicad_sch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]
2025-03-02 Fixing D6 - Adding long press
    [main.c]
2025-03-08 Adding schematics
2025-04-11 uređena schema
    [ZigZag.kicad_sch]

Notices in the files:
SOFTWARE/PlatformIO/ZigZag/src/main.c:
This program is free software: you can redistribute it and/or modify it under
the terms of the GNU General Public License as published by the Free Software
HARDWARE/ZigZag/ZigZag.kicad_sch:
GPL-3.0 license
